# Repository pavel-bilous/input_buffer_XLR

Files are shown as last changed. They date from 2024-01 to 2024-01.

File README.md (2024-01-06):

# Input buffer for amplifier with balanced inputs

This buffer serves as an impedance matching and is implemented on the board that allows for balanced XLR inputs for two channels.

## PCB rendered in 3d:
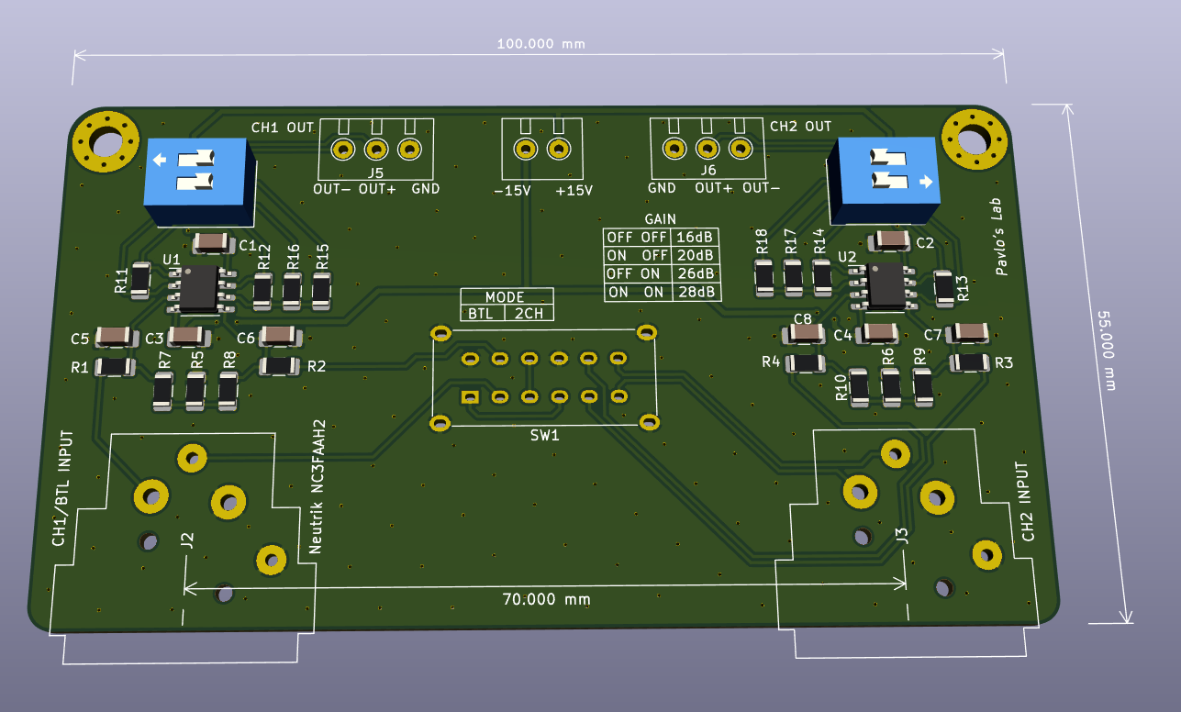
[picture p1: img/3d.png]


## Schematics:

Opamps can be NE5532 or LM4562 or any other with good unity gain stability. Preferred opamp with superior open loop gain is OPA1656.

Input XLR connectors are Neutrik NC3FAAH2.

Capacitors for input low pass filters are C0G or NP0 type. Decoupling capacitors are X7R 100nF or higher (1uF will work great).

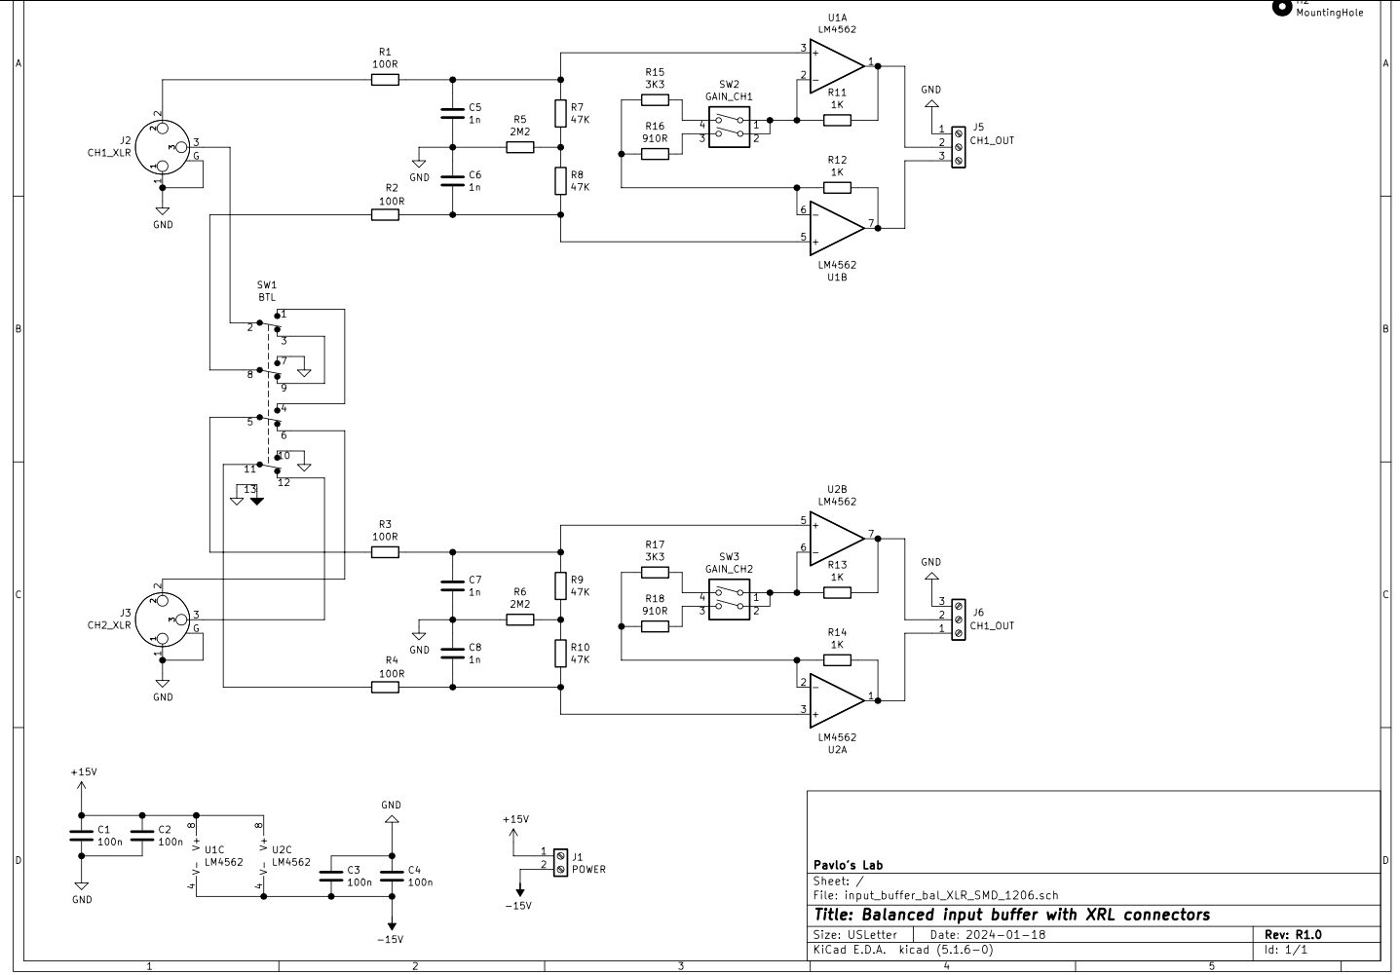
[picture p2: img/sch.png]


## PCB layout:

Bottom layer is GND. Top layer is signal + power and GND poured in between. Stiching vias are then applied to connect bottom and top GND planes to ensure those are as close to 0 as possible.

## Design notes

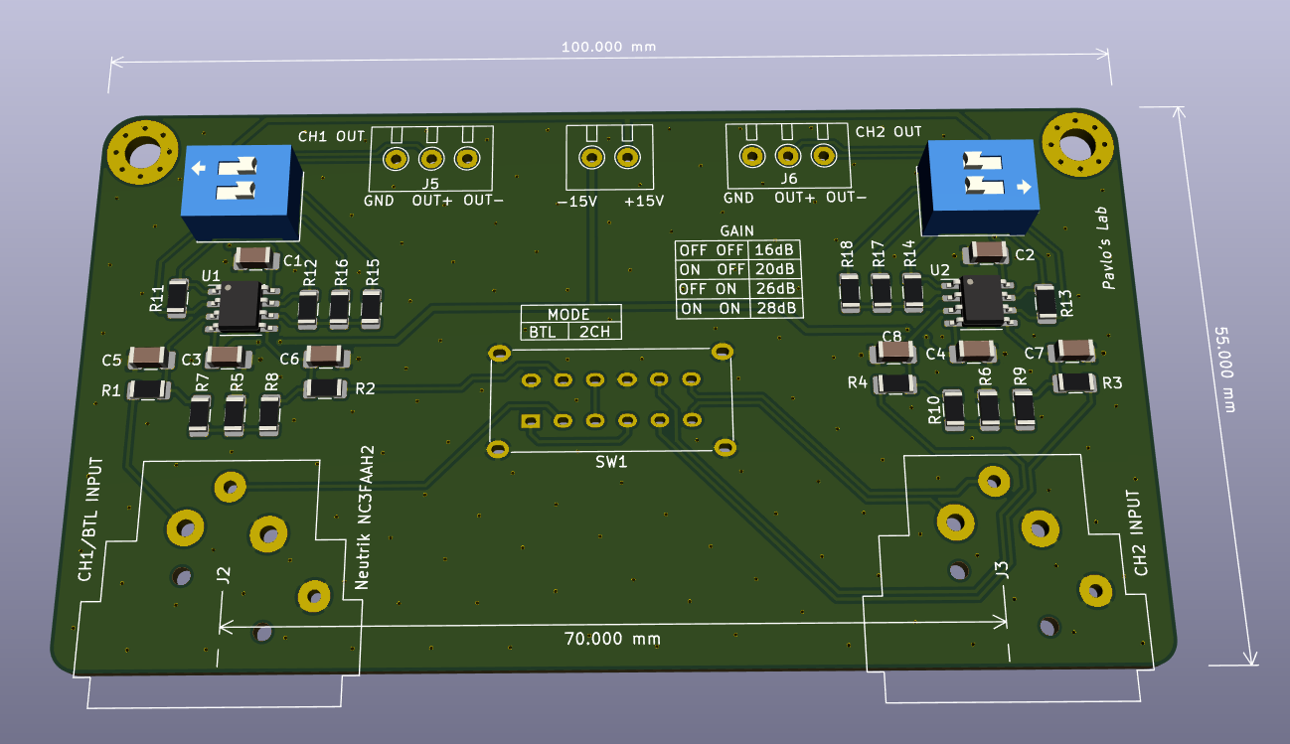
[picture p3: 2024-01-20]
img/pcb.png

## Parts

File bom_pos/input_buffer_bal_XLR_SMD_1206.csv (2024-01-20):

Id | Designator | Package | Quantity | Designation | Supplier and ref
1 | SW1 | SW_SS-42H11_4PDT | 1 | BTL
2 | SW3 | SW_DIP_SPSTx02_Slide_W7.62mm_P2.54mm | 1 | GAIN_CH2
3 | SW2 | SW_DIP_SPSTx02_Slide_W7.62mm_P2.54mm | 1 | GAIN_CH1
4 | R18,R16 | R_1206_3216Metric | 2 | 910R
5 | R17,R15 | R_1206_3216Metric | 2 | 3K3
6 | J6,J5 | TerminalBlock_ Amphenol_01_03_P3.50mm | 2 | CH1_OUT
7 | U2,U1 | SOIC-8_3.9x4.9mm_P1.27mm | 2 | LM4562
8 | R14,R13,R12,R11 | R_1206_3216Metric | 4 | 1K
9 | R10,R9,R8,R7 | R_1206_3216Metric | 4 | 47K
10 | R6,R5 | R_1206_3216Metric | 2 | 2M2
11 | R4,R3,R2,R1 | R_1206_3216Metric | 4 | 100R
12 | J3 | Jack_XLR_Neutrik_NC3FAAH2_Horizontal_centered | 1 | CH2_XLR
13 | C8,C7,C6,C5 | C_1206_3216Metric_Pad1.42x1.75mm_HandSolder | 4 | 1n
14 | J1 | TerminalBlock_ Amphenol_01_02_P3.50mm | 1 | POWER
15 | C4,C3,C2,C1 | C_1206_3216Metric_Pad1.42x1.75mm_HandSolder | 4 | 100n
16 | H2,H1 | MountingHole_3.5mm_Pad_Via | 2 | MountingHole
17 | J2 | Jack_XLR_Neutrik_NC3FAAH2_Horizontal_centered | 1 | CH1_XLR

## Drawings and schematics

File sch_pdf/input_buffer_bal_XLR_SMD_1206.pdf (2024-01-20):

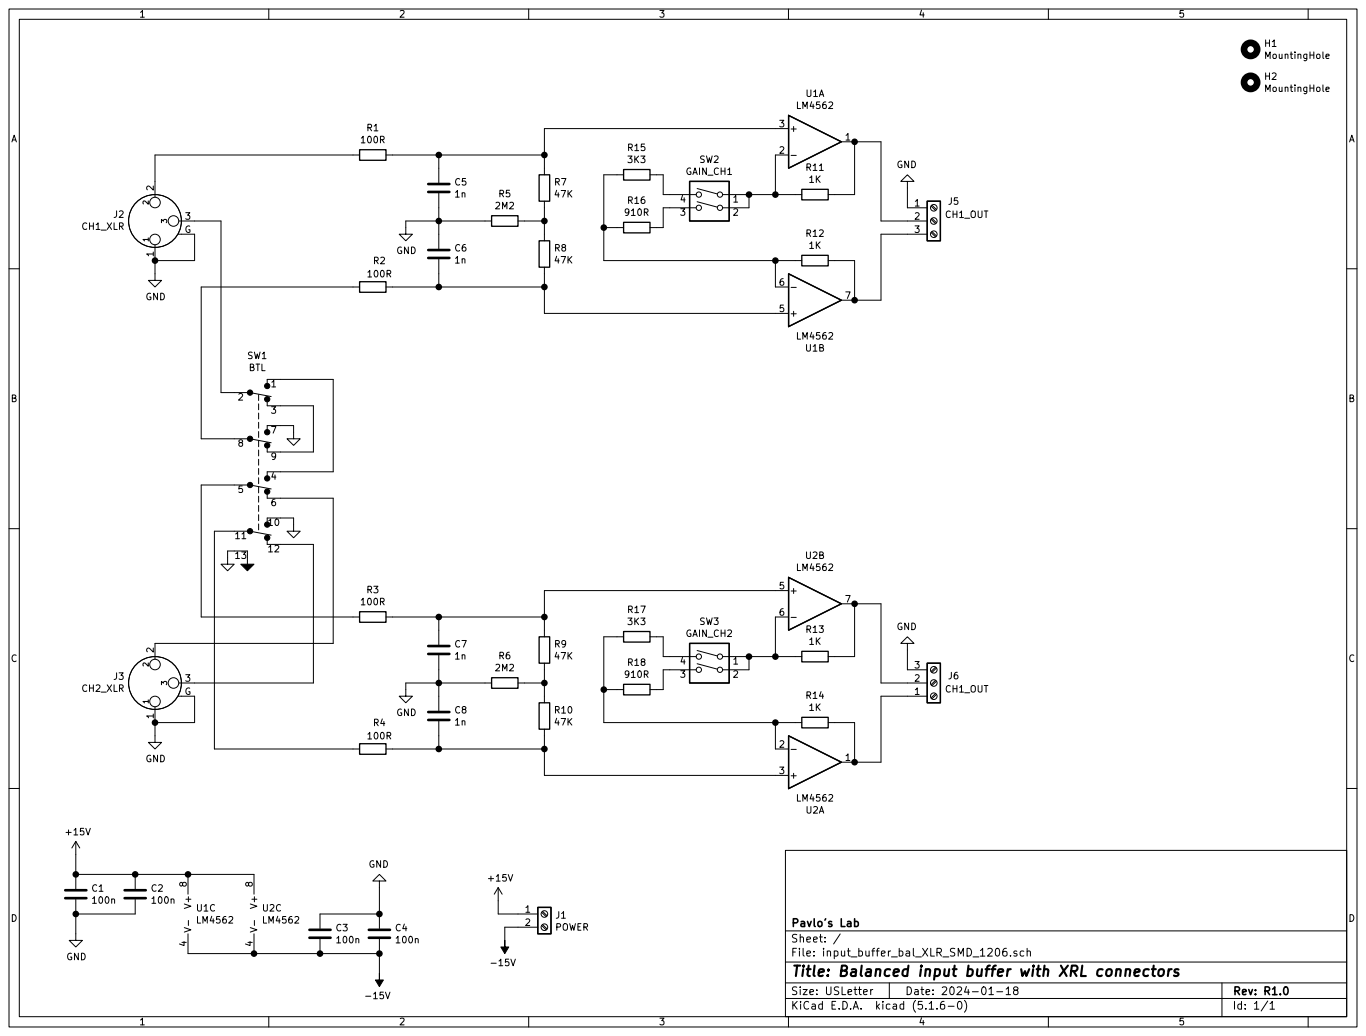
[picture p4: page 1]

File: input_buffer_bal_XLR_SMD_1206.sch Sheet: / Pavlo's Lab

Id: 1/1 Title: Balanced input buffer with XRL connectors

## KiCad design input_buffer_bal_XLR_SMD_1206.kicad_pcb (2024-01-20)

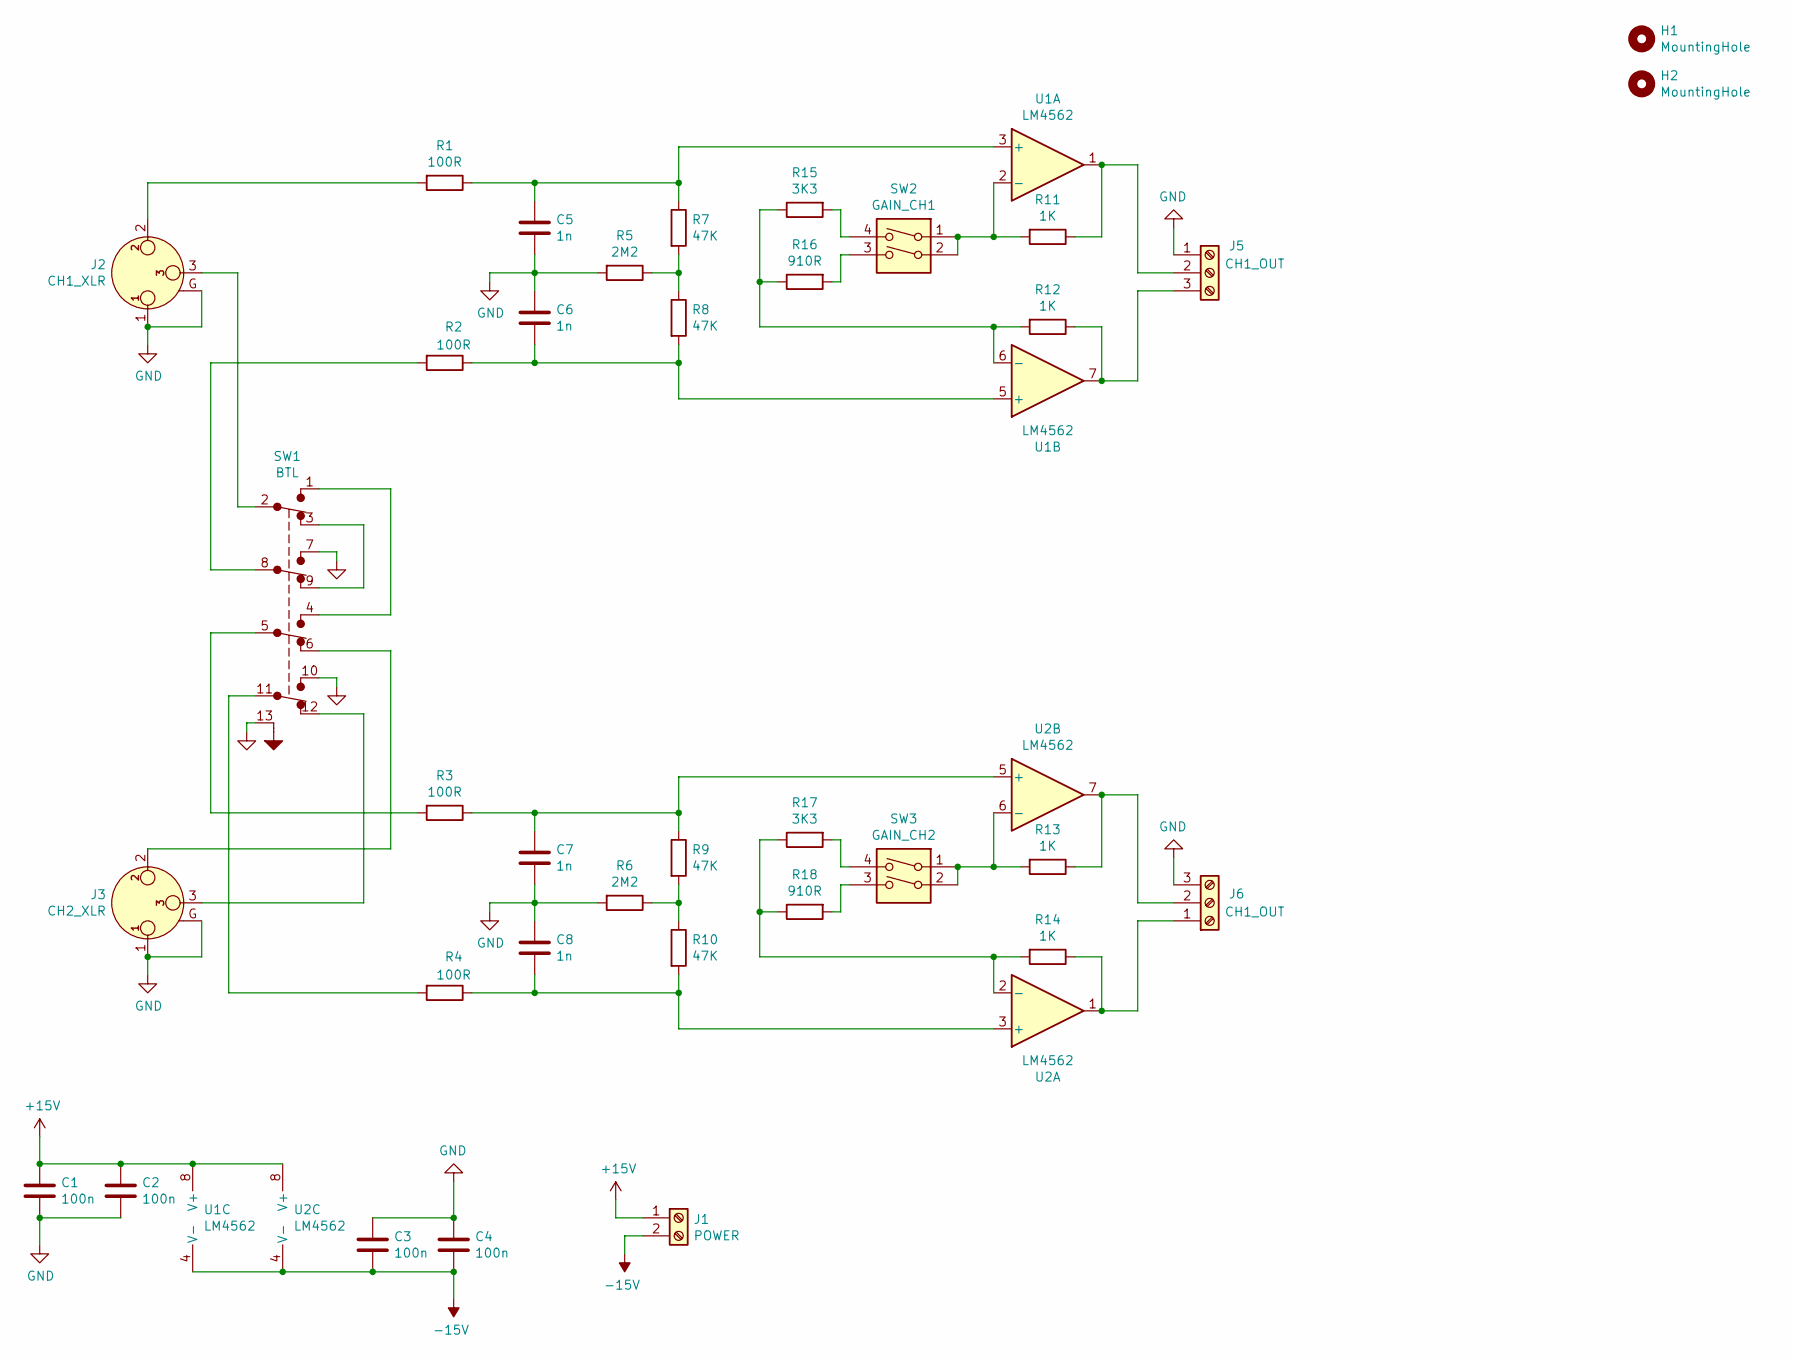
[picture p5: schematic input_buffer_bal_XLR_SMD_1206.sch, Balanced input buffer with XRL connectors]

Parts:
C1, C2, C3, C4: 100n; C_1206_3216Metric_Pad1.42x1.75mm_HandSolder
C5, C6, C7, C8: 1n; C_1206_3216Metric_Pad1.42x1.75mm_HandSolder
H1, H2: MountingHole; MountingHole_3.5mm_Pad_Via
J1: POWER; TerminalBlock_ Amphenol_01_02_P3.50mm
J2: CH1_XLR; Jack_XLR_Neutrik_NC3FAAH2_Horizontal_centered
J3: CH2_XLR; Jack_XLR_Neutrik_NC3FAAH2_Horizontal_centered
J5, J6: CH1_OUT; TerminalBlock_ Amphenol_01_03_P3.50mm
R1, R2, R3, R4: 100R; R_1206_3216Metric
R5, R6: 2M2; R_1206_3216Metric
R7, R8, R9, R10: 47K; R_1206_3216Metric
R11, R12, R13, R14: 1K; R_1206_3216Metric
R15, R17: 3K3; R_1206_3216Metric
R16, R18: 910R; R_1206_3216Metric
SW1: BTL; SW_SS-42H11_4PDT
SW2: GAIN_CH1; SW_DIP_SPSTx02_Slide_W7.62mm_P2.54mm
SW3: GAIN_CH2; SW_DIP_SPSTx02_Slide_W7.62mm_P2.54mm
U1, U2: LM4562; SOIC-8_3.9x4.9mm_P1.27mm

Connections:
+15V: C1.1, C2.1, J1.1, U1.8 (V+), U2.8 (V+)
-15V: C3.2, C4.2, J1.2, U1.4 (V-), U2.4 (V-)
GND: C1.2, C2.2, C3.1, C4.1, C5.2, C6.1, C7.2, C8.1, J2.1, J2.G, J3.1, J3.G, J5.1, J6.3, R5.2, R6.2, SW1.7 (A), SW1.10 (A), SW1.13 (GND)
unnamed: C5.1, R1.1, R7.1, U1.3 (+)
unnamed: C6.2, R2.1, R8.2, U1.5 (+)
unnamed: C7.1, R3.1, R9.1, U2.5 (+)
unnamed: C8.2, R4.1, R10.2, U2.3 (+)
unnamed: J2.2, R1.2
unnamed: J2.3, SW1.2 (B)
unnamed: J3.2, SW1.6 (C)
unnamed: J3.3, SW1.12 (C)
unnamed: J5.2, R11.1, U1.1
unnamed: J5.3, R12.1, U1.7
unnamed: J6.1, R14.1, U2.1
unnamed: J6.2, R13.1, U2.7
unnamed: R2.2, SW1.8 (B)
unnamed: R3.2, SW1.5 (B)
unnamed: R4.2, SW1.11 (B)
unnamed: R5.1, R7.2, R8.1
unnamed: R6.1, R9.2, R10.1
unnamed: R11.2, SW2.1, SW2.2, U1.2 (-)
unnamed: R12.2, R15.1, R16.1, U1.6 (-)
unnamed: R13.2, SW3.1, SW3.2, U2.6 (-)
unnamed: R14.2, R17.1, R18.1, U2.2 (-)
unnamed: R15.2, SW2.4
unnamed: R16.2, SW2.3
unnamed: R17.2, SW3.4
unnamed: R18.2, SW3.3
unnamed: SW1.1 (A), SW1.4 (A)
unnamed: SW1.3 (C), SW1.9 (C)

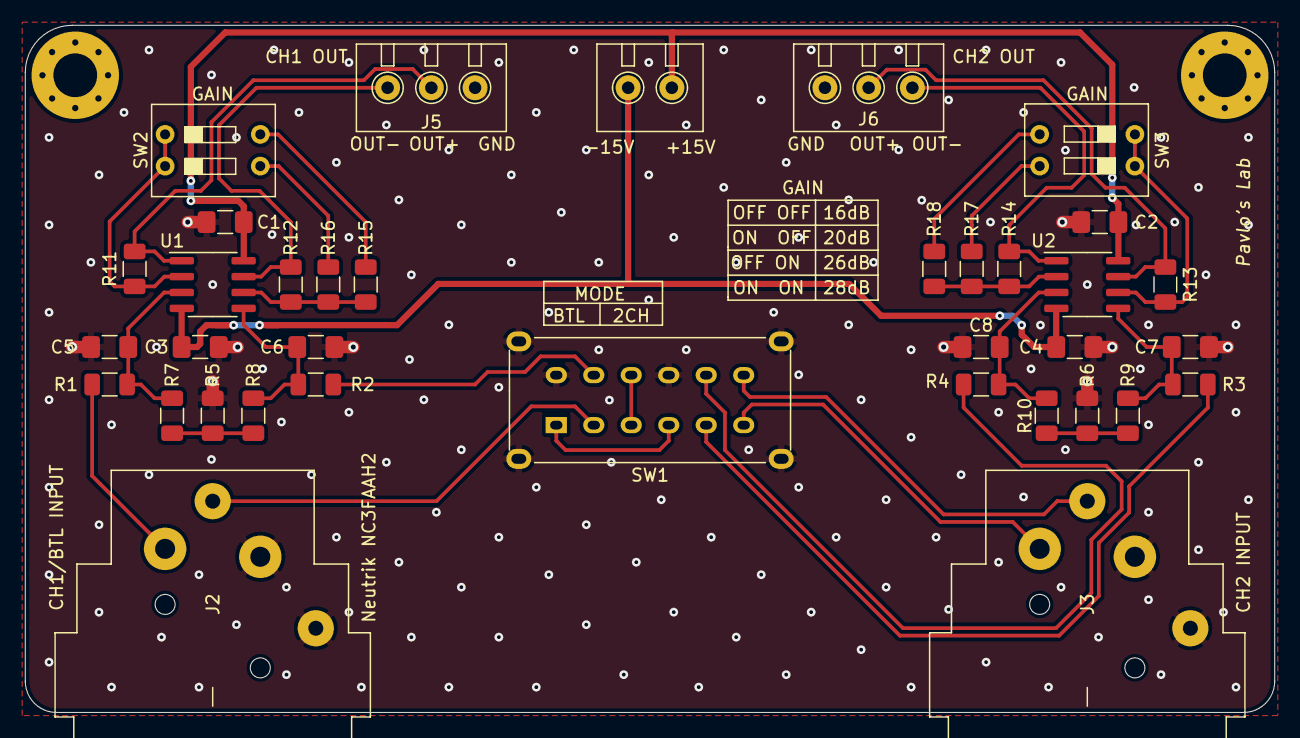
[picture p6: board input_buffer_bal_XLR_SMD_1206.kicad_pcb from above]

Board: 2 copper layers, 100.0 x 55.0 mm, 38 parts (0 on the bottom side), 30 nets.

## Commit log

2023-04-17 added project files
    [input_buffer_bal_XLR-B_Cu.gbr, input_buffer_bal_XLR-B_Mask.gbr, input_buffer_bal_XLR-B_Paste.gbr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]
2023-05-06 rev1.1 fixes major issues with the pcb layout
    [input_buffer_bal_XLR_SMD_1206-B_Cu.gbr, input_buffer_bal_XLR_SMD_1206-B_Mask.gbr, input_buffer_bal_XLR_SMD_1206-B_Paste.gbr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]
2023-05-06 updated pos files
    [input_buffer_bal_XLR_SMD_1206.csv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]
2023-05-06 updated gerber files
    [input_buffer_bal_XLR_SMD_1206-B_Cu.gbr, input_buffer_bal_XLR_SMD_1206-B_Mask.gbr, input_buffer_bal_XLR_SMD_1206-B_Paste.gbr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]
2023-06-01 rev1.2 changed power connector
    [input_buffer_bal_XLR_SMD_1206-B_Cu.gbr, input_buffer_bal_XLR_SMD_1206-B_Mask.gbr, input_buffer_bal_XLR_SMD_1206-B_Paste.gbr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]
2024-01-06 revised with added option to change gain
    [input_buffer_bal_XLR_SMD_1206-B_Cu.gbr, input_buffer_bal_XLR_SMD_1206-B_Mask.gbr, input_buffer_bal_XLR_SMD_1206-B_Paste.gbr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]
2024-01-06 grb updated
    [input_buffer_bal_XLR_SMD_1206-B_Cu.gbr, input_buffer_bal_XLR_SMD_1206-B_Mask.gbr, input_buffer_bal_XLR_SMD_1206-B_Paste.gbr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]
2024-01-09 added bom
    [input_buffer_bal_XLR_SMD_1206.csv]
2024-01-19 footprints updates
    [input_buffer_bal_XLR_SMD_1206.kicad_pcb, input_buffer_bal_XLR_SMD_1206.sch]
2024-01-20 finished layout
    [input_buffer_bal_XLR_SMD_1206-B_Cu.gbr, input_buffer_bal_XLR_SMD_1206-B_Mask.gbr, input_buffer_bal_XLR_SMD_1206-B_Paste.gbr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]
2024-01-20 updated gerbers
    [input_buffer_bal_XLR_SMD_1206-B_Cu.gbr, input_buffer_bal_XLR_SMD_1206-B_Mask.gbr, input_buffer_bal_XLR_SMD_1206-B_Paste.gbr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]
